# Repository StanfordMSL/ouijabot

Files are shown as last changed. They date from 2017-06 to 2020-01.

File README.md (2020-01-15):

# ouijabot

The ouijabot is an omnidirectional ground robot platform designed for general experiments in the plane, including 2D SLAM, collaborative manipulation, and pursuit-evasion. The platform's holonomic dynamics allow it to be well-modeled with a single-integrator model, which make it ideal for a wide variety of planar control and navigation tasks.

The hardware consists of 4 DC motors, which drive omnidirectional wheels, and an embedded Linux computer (Raspberry Pi). This project aims to completely open source all software and hardware. All communication is performed using ROS.

## Supported functions
Below are the features or capabilities of the ouijabot which
are currently supported.

---

### Onboard functions:
#### Velocity control
* Open-loop controller which seeks to track a desired robot velocity
  (combined linear and angular velocity).

#### Force control
* Closed-loop controller, which uses onboard current sensors to
  generate desired wrench (force and torque).

#### Sensors
* Measures current supplied to each motor by the motor drivers.
* Measures current linear acceleration and angular velocity via onboard IMU.

---
### Offboard functions:
#### Velocity teleoperation:
* ROS node which generates and publishes body-frame velocity
  commands via joystick input.

#### Force teleoperation:
* ROS node which generates and publishes body-frame force and torque commands
  via joystick input.

## Basic usage
Below we provide general instructions for how to utilize the supported features detailed above. Please see the code for additional details. All nodes typically run in a namespace set by the user's `$HOSTNAME` variable.

---

#### Velocity control
* **Onboard:** run `roslaunch ouijabot velocity_control.launch` to start the velocity control node (`velocity_control.py`). The node will subscribe to the topic `cmd_vel`, which uses messages of type `geometry_msgs/Twist`.
  * **Arguments:**
    * `cmdMode`: flag for desired throttle response of ouijabot. If set to `"equal"`, command axes are decoupled; throttle commands in one axis always correspond to the same speed, regardless of other axis commands. If set to `"max"`, then any command with l1-norm >= 1 is treated as "full speed"; at least one motor will run at max RPM. Allows for faster speeds overall of the ouijabot, but with less physical intuition behind commands.

* **Offboard:** to teleoperate ouijabot, run `roslaunch ouijabot_telop vel_telop.launch` to launch the velocity command node. The node will read joystick inputs and use them to generate velocity commands, which it publishes to `cmd_vel`.
  * **Arguments:**
    * `id`: index of ouijabot to be commanded. The node will remap the generic `cmd_vel` topic to `/ouijabot$(arg id)/cmd_vel` by default. Defaults to `1`.
    * `velMax_l`: scaling parameter for linear velocity commands. Should range between `0` and `1`, with `1` corresponding to max throttle available in hardware. Defaults to `1.0`.
    * `velMax_a`: scaling parameter for angular velocity commands. Same behavior as linear velocity scaling; defaults to `1.0`.
---
#### Force control
* **Onboard:** run `roslaunch ouijabot force_control.launch` to launch the force control node (`force_control.py`). The node will subscribe to the topic `cmd_wrench` which uses messages of type `geometry_msgs/Twist`. It uses onboard current sensors to run a closed-loop PID controller to generate the desired wrench.

    __*Note:*__ *`params.launch` must be run before `force_control.launch`; the PID parameters are set as ROS parameters in this file. This is typically done once, offboard, as part of robot setup. These parameters may easily be tuned by setting the ROS parameters manually.*

* **Offboard:** run `roslaunch ouijabot params.launch`, once, to set force controller parameters. Then run `roslaunch ouijabot_telop force_telop.launch` to teleoperate the ouijabot in force control mode. The node will read joystick inputs and use them to generate wrench commands, which it publishes to `cmd_wrench`.
  * **Arguments:**
    * `id`: index of ouijabot to be commanded. The node will remap the generic `cmd_vel` topic to `/ouijabot$(arg id)/cmd_vel` by default. Defaults to `1`.
    * `force_scale`: scaling parameter for max force command, in Newtons. Defaults to `100.0`.
    * `torque_scale`: scaling parameter for max torque command, in Newton-meters. Defaults to `5.0`.

---

#### Sensor readings
* **Current sensors:** run `roslaunch ouijabot current_read.launch` to run the current sensor node `current_read.py`. The node reads the current sensors on the motor controllers and publishes the values to the topic `current` as a vector of floats.

    __*Note:*__ *Do not run `current_read.py` at the same time as `force_control.py`; the force control node reads/publishes the current sensors as part of its control loop and the conflicting reads could cause timing errors.

* **IMU:** run `roslaunch ouijabot imu_read.launch` to run the IMU node `imu_read.py`. The node will read measurements from the IMU over I2C and publish them to the topic `imu` as messages of type `sensor_msgs/Imu`.

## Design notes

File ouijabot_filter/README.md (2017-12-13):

ouijabot_filter
===============

Author: Eric Cristofalo

Affiliation: Stanford University

Date Created: 2017/08/17; Date Last Modified: 2017/08/17

Tested on: ROS Kinetic

# Required ROS Packages:
* mocap_optitrack
* mocap_interface
* rviz
* rqt
* ouijabot_telop_cpp

# ouijabot_filter
This package contains an node that estimates the pose and odometry of the Ouijabot from published Optitrack data and the onboard IMU/wheel encoders. The estimation is performed with an EKF using the holonomic robot's 2nd order motion model. 

## Requirements

## Files
* filter.cpp
	* Reads raw Ouijabot data and Optitrack data to estimate odometry
    * Publishes ground truth odometry from Optitrack and estimated odometry from Ouijabot sensor data 
    * display_data_flag: integer indicator for printing data during testing (1 displays data)
    * use_optitrack_flag: integer indicator for dusing motion capture data into odometry estimate (not yet functional)
		* wheel_radius
		* body_radius
    * pos_covariance: double for position covariance
    * orient_covariance: double for orientation covariance
    * vel_covariance: double for velocity covariance
    * rot_rate_covariance: double for rotation rate covariance
    * accel_covariance: double for acceleration covariance
    * ROT_accel_covariance: double for rotation acceleration covariance
		* wheel_measurement_covariance
		* gyro_measurement_covariance
		* accel_measurement_covariance

* filter.launch
    * ROS launch file that launches the mocap_optitrack, rviz, rqt, and filter nodes simulaneously. The ground truth and odometry estimates are visualized in RViz. The state estimate is plotted against the ground truth using rqt.

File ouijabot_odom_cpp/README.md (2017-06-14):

ouijabot_odom_cpp
===============

Author: Eric Cristofalo

Affiliation: Stanford University

Date Created: 2017/06/13; Date Last Modified: 2017/06/13

Tested on: ROS Kinetic

# Required ROS Packages:
* mocap_optitrack
* mocap_interface
* joy
* rviz
* ouijabot_telop_cpp

# ouijabot_odom_cpp
This package contains an node that estimates the odometry of the Ouijabot from published wheel velocities. In the future, we should add a Kalman filter to fuse wheel encoders, IMU, and noisy GPS (motion capture) data.  

## Requirements

## Files
* odom.cpp
	* Reads raw Ouijabot data and Optitrack data to estimate odometry
    * Publishes ground truth odometry from Optitrack and estimated odometry from Ouijabot sensor data 
    * DISPLAY_DATA_BOOL: integer indicator for printing data during testing (1 displays data)
    * USE_OPTITRACK_BOOL: integer indicator for dusing motion capture data into odometry estimate (not yet functional)
    * POSITION_COVARIANCE: double for position covariance
    * ORIENTATION_COVARIANCE: double for orientation covariance
    * VELOCITY_COVARIANCE: double for velocity covariance
    * ROTATION_RATE_COVARIANCE: double for rotation rate covariance
* odom.launch
    * ROS launch file that launches the mocap_optitrack, rviz, and odom nodes simulaneously. The ground truth and odometry estimates are visualized in RViz.

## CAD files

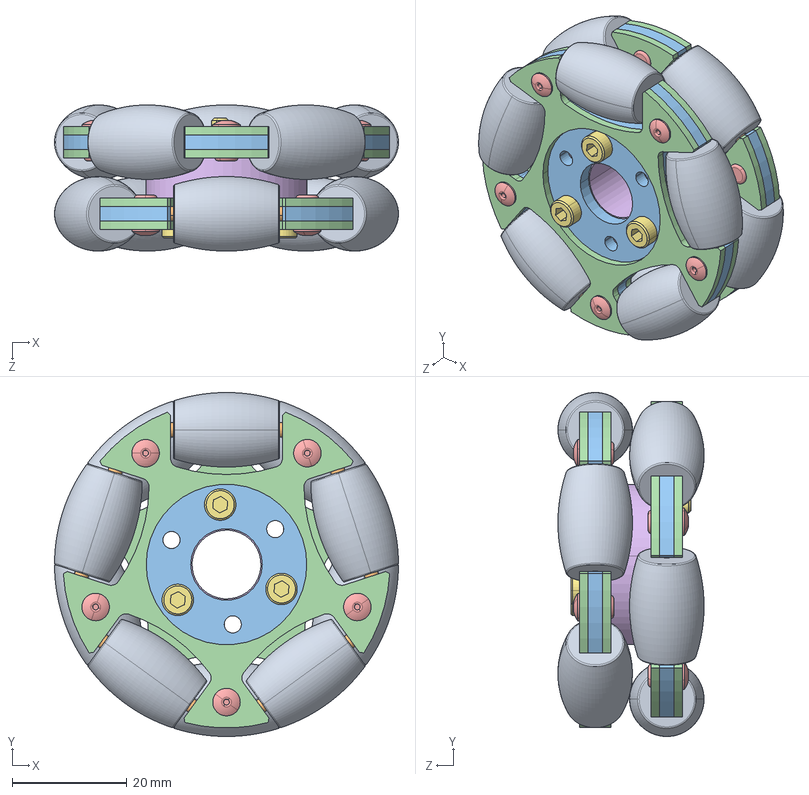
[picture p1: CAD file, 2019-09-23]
Hardware/CAD/omni-wheel-60mm.SLDASM
60.0 x 60.0 x 25.5 mm
60mm90__5______-______(A__).STEP x 10
60mm90__5______-______-__(A__).STEP x 10
60mm90__5______-____________(A__).STEP x 2
60mm90__5______-__________(A__).STEP x 4
____3X5.STEP x 10
60mm90__5______-__________(A__)-0.STEP
__________(M3X20).STEP x 3

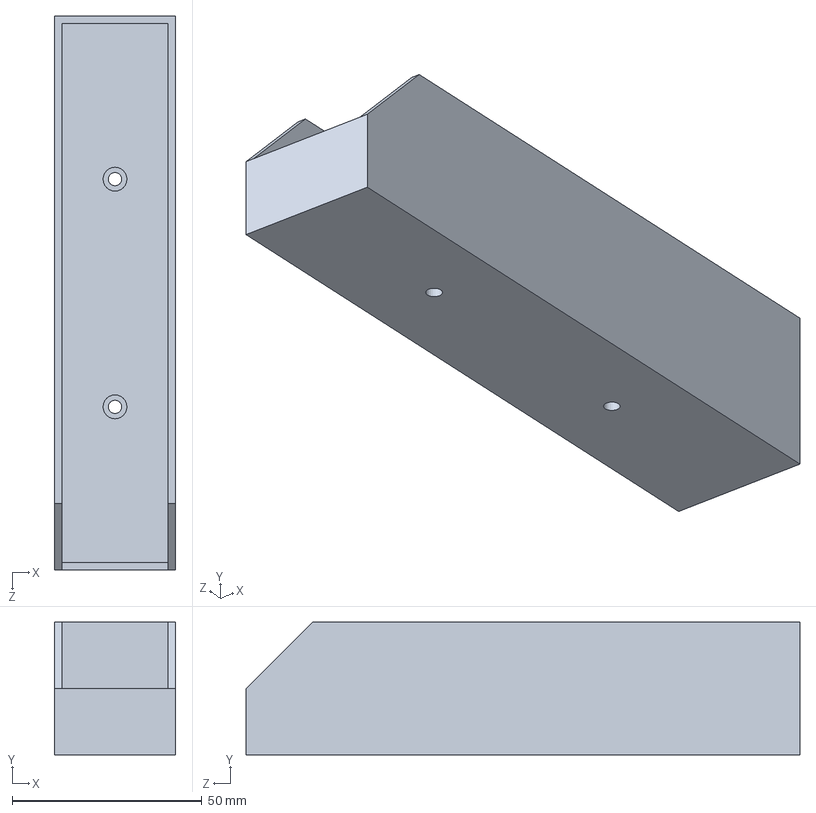
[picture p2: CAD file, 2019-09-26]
Hardware/CAD/battery-holder.SLDPRT
32.0 x 35.0 x 146.0 mm

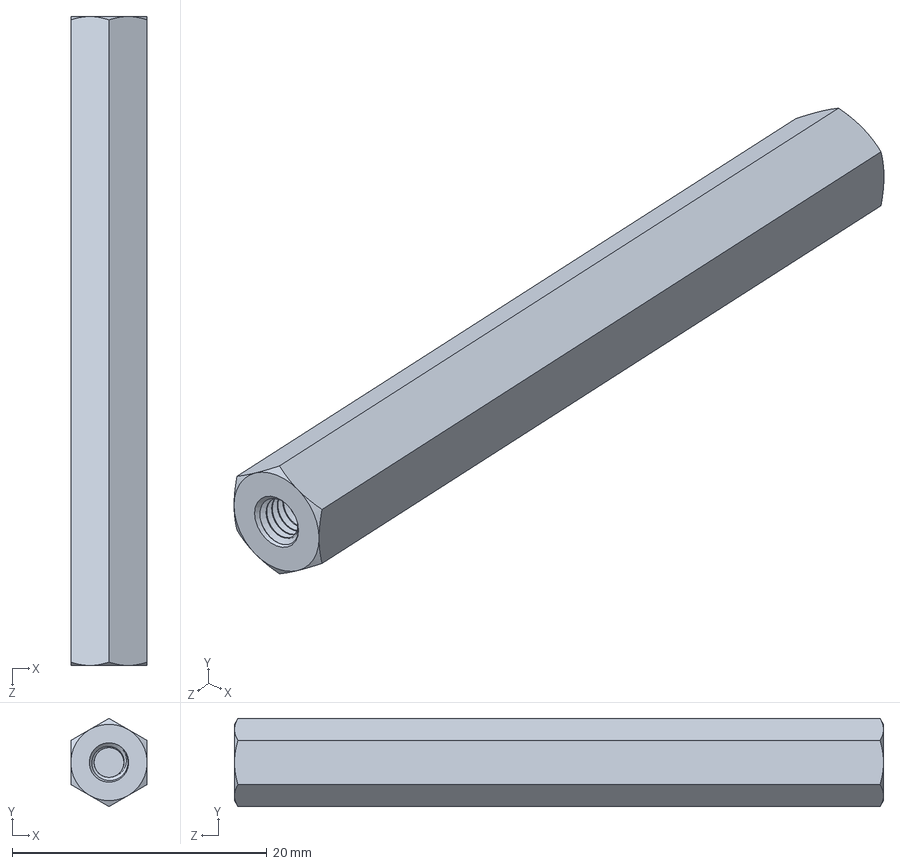
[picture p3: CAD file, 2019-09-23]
Hardware/CAD/standoff-51mm.SLDPRT
6.00 x 6.93 x 51.0 mm

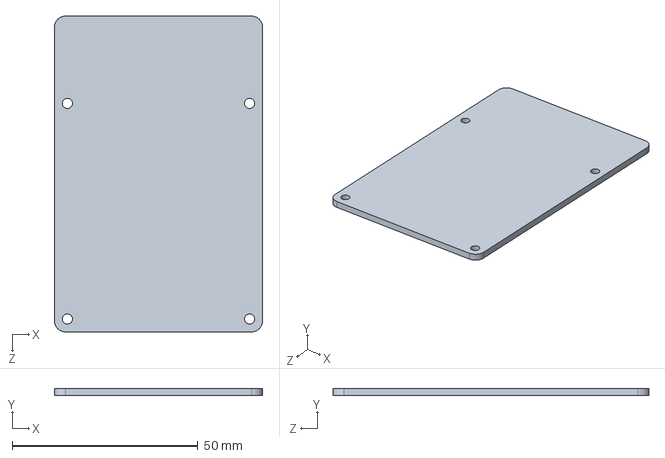
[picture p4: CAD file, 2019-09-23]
Hardware/CAD/raspberry_pi.SLDPRT
56.0 x 2.00 x 85.0 mm

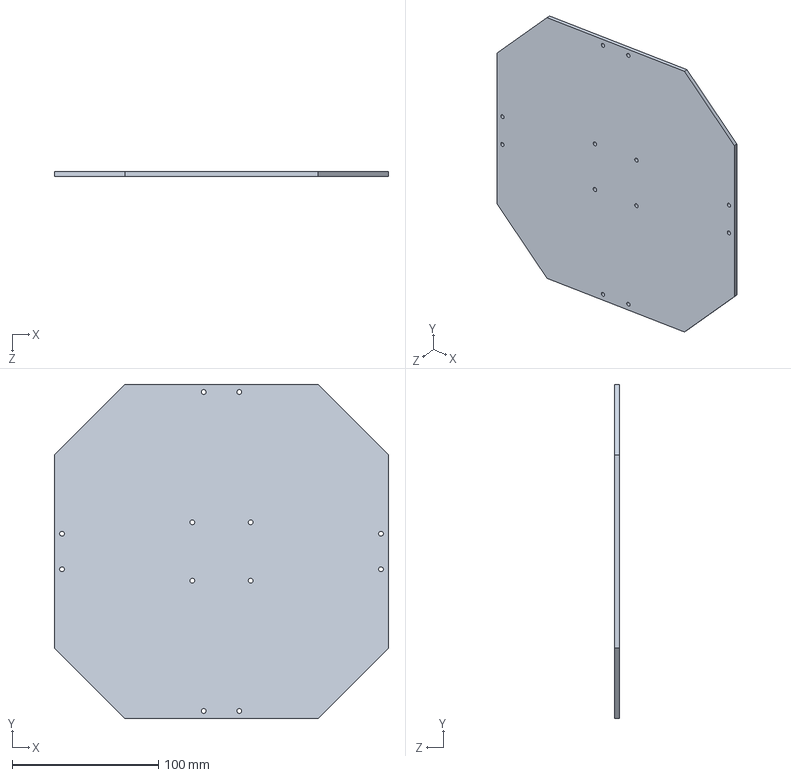
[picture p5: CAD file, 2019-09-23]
Hardware/CAD/lid.sldprt
228.6 x 228.6 x 3.17 mm

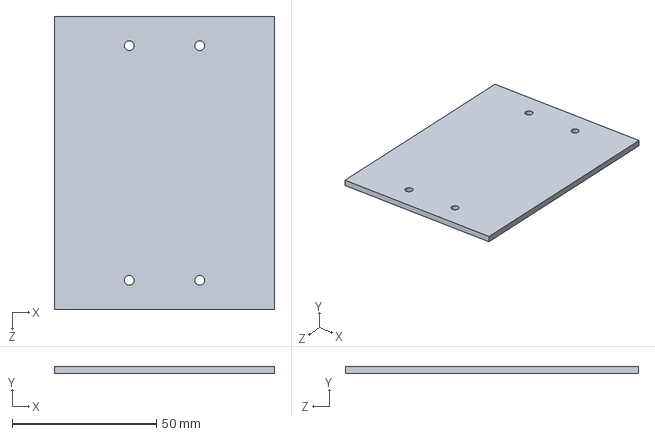
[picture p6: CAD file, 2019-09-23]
Hardware/CAD/wall.SLDPRT
76.2 x 2.54 x 101.6 mm

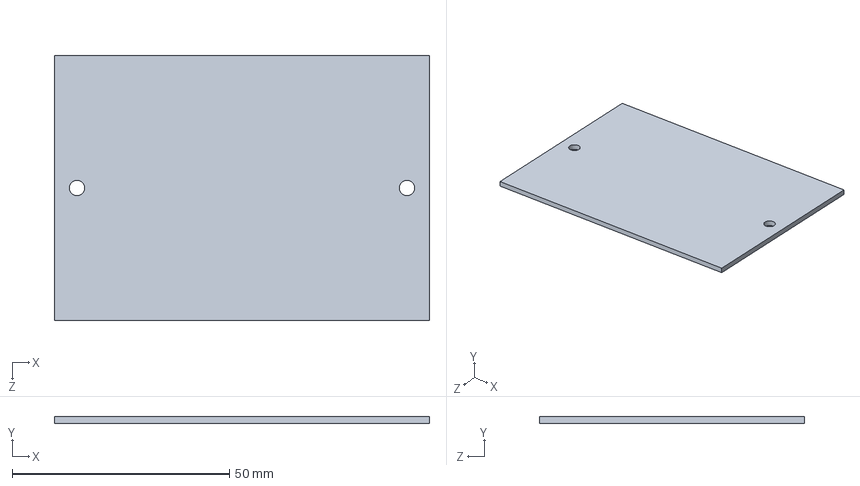
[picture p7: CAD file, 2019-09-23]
Hardware/CAD/protoboard.SLDPRT
86.4 x 1.60 x 61.0 mm

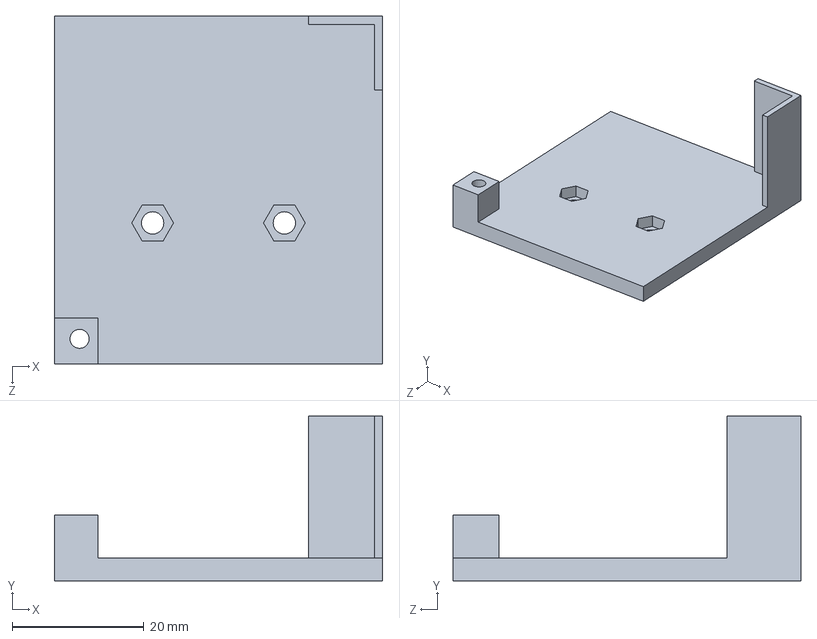
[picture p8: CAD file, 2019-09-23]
Hardware/CAD/motor-controller-holder-arduino-horizontal.SLDPRT
49.8 x 25.0 x 52.8 mm

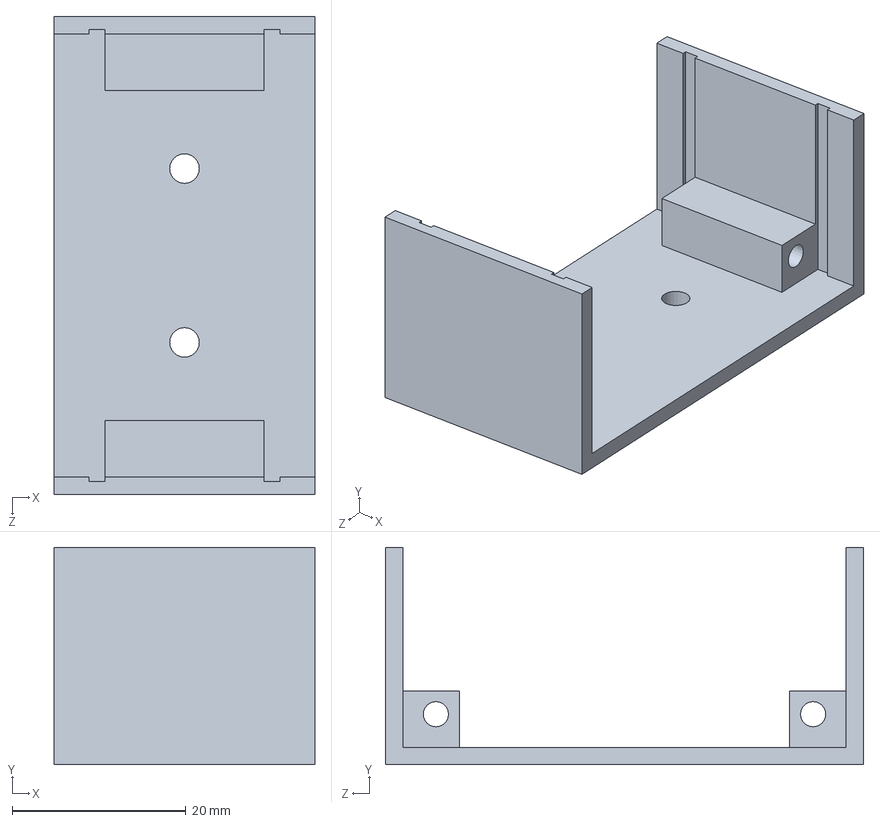
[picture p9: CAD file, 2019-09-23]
Hardware/CAD/motor-controller-holder-arduino.SLDPRT
30.0 x 25.0 x 55.0 mm

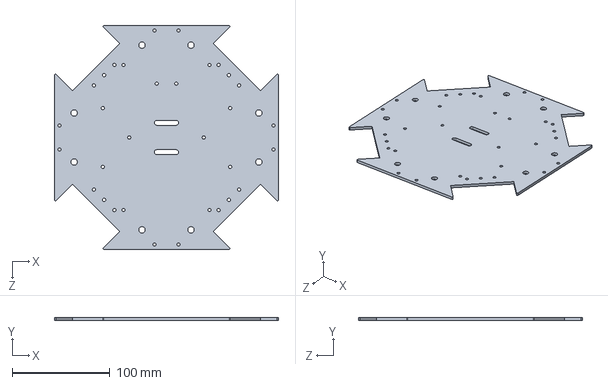
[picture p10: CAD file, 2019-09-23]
Hardware/CAD/base.SLDPRT
228.6 x 3.00 x 228.6 mm

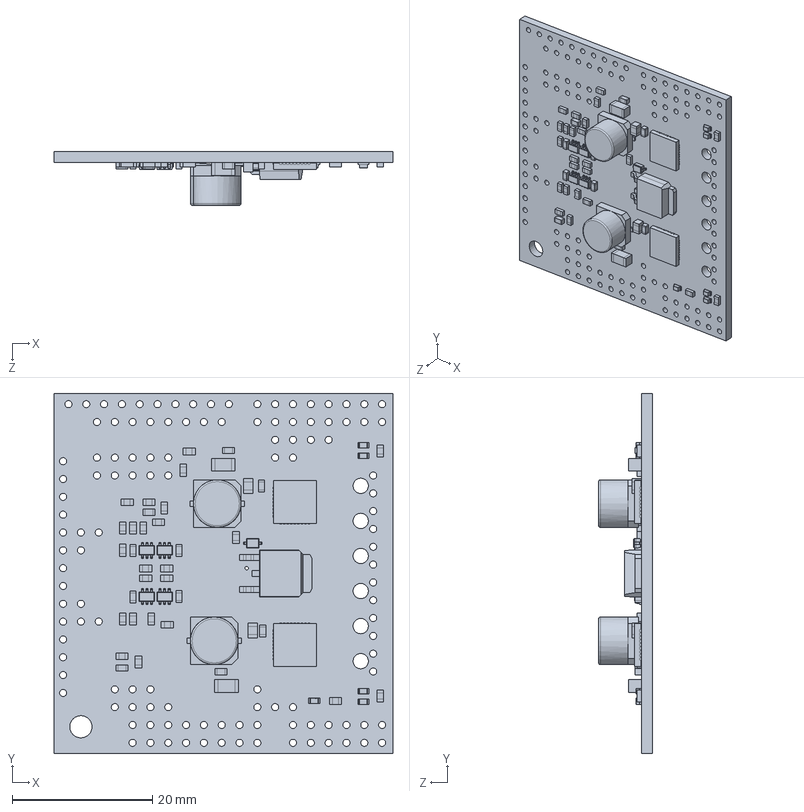
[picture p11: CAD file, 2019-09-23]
Hardware/CAD/motor-driver-pololu-tb9051ftg.SLDPRT
48.3 x 51.3 x 7.67 mm

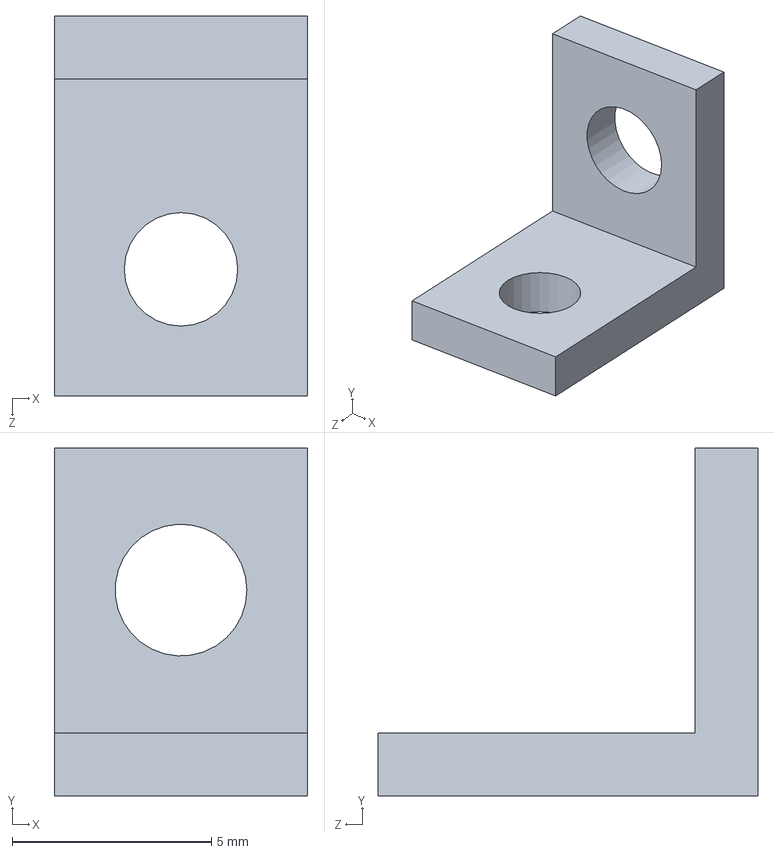
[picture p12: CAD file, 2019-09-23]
Hardware/CAD/angle-bracket.SLDPRT
6.35 x 8.71 x 9.53 mm

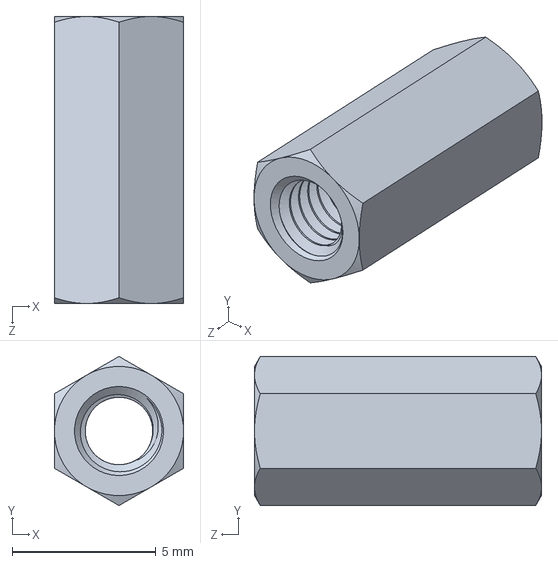
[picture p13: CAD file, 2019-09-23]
Hardware/CAD/standoff-10mm.SLDPRT
4.50 x 5.20 x 10.0 mm

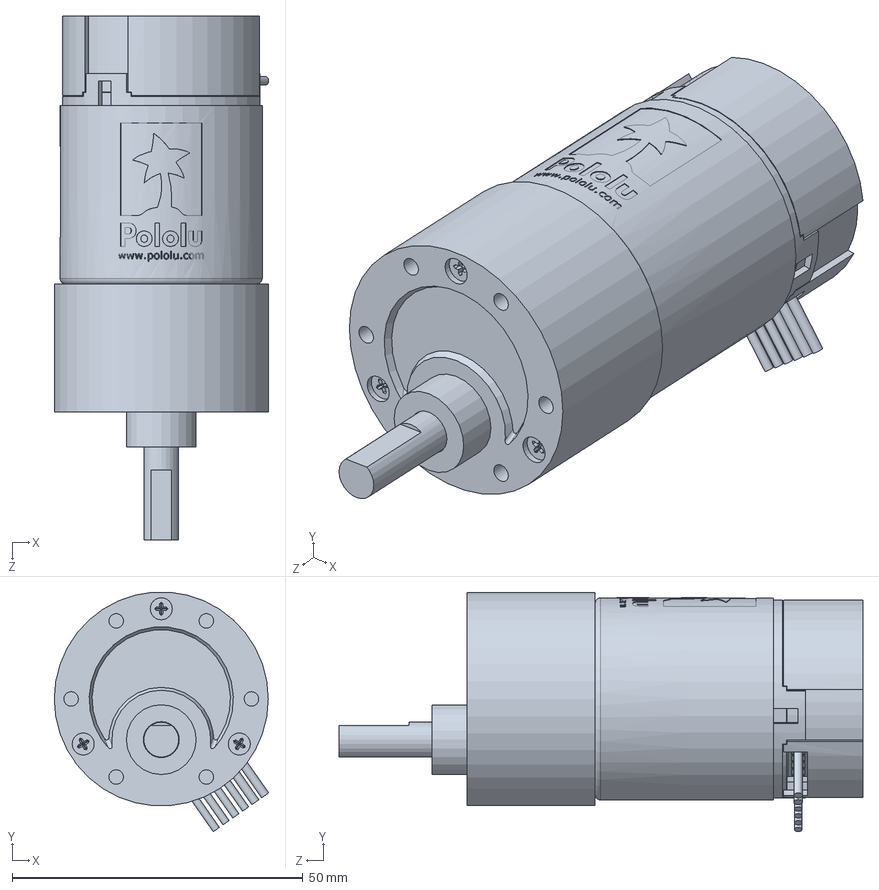
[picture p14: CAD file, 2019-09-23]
Hardware/CAD/motor-pololu-2823.SLDPRT
36.9 x 41.2 x 90.1 mm

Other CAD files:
Hardware/CAD/motor-mount-pololu-1995.SLDPRT
Hardware/CAD/level2-plate.SLDPRT

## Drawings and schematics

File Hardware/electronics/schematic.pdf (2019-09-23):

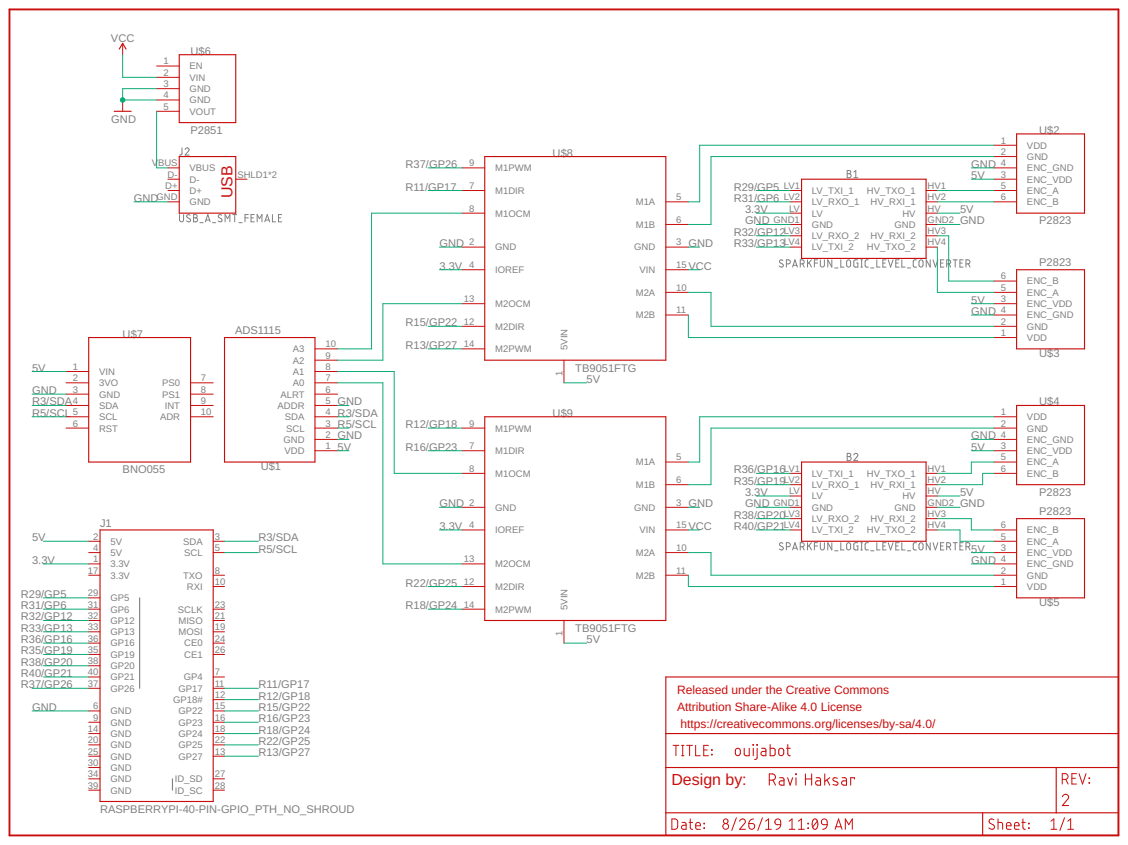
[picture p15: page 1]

Released under the Creative Commons Attribution Share-Alike 4.0 License

https://creativecommons.org/licenses/by-sa/4.0/

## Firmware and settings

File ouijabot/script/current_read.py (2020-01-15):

#!/usr/bin/python3

"""ROS node which reads and publishes current sensor values.

Module uses adafruit packages to read current sensors from motor control boards
over I2C. Uses a try-except block to catch bad I2C reads. Publishes current
values to the 'current' topic under the node's namespace.
"""

import rospy
import board
import busio
import adafruit_ads1x15.ads1015 as ADS
from adafruit_ads1x15.analog_in import AnalogIn
from std_msgs.msg import Float64MultiArray

i2c = busio.I2C(board.SCL, board.SDA) #create i2c object
ads = ADS.ADS1015(i2c) #create ads object

#setup channels for each current sensor
chan0 = AnalogIn(ads,ADS.P0)
chan1 = AnalogIn(ads,ADS.P1)
chan2 = AnalogIn(ads,ADS.P2)
chan3 = AnalogIn(ads,ADS.P3)

if __name__=="__main__":
	rospy.init_node('current')
	pub = rospy.Publisher('current',Float64MultiArray,queue_size=10)
	r = rospy.Rate(100) #TODO(Preston): make this a ROS parameter
	while not rospy.is_shutdown():
        try: #try to read current sensor
            msg = Float64MultiArray(data=[chan0.voltage,chan1.voltage,chan2.voltage,chan3.voltage])
            pub.publish(msg)
        except: #this read can fail; 
            rospy.logwarn('current read error')
		r.sleep()

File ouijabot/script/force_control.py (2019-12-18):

#!/usr/bin/env python3
import RPi.GPIO as io
import rospy
import numpy as np

from geometry_msgs.msg import Twist

import board
import busio
import adafruit_ads1x15.ads1015 as ADS
from adafruit_ads1x15.analog_in import AnalogIn
from std_msgs.msg import Float64MultiArray

sign = lambda x: (1,-1)[x<0]


class Ouijabot():
	def __init__(self):
		self.pwm_nos = [26,27,18,24]
		self.dir_pins = [17,22,23,25]
		self.pwm_pins = []
		for i in range(0,4):
			io.setup(self.pwm_nos[i],io.OUT)
			io.setup(self.dir_pins[i],io.OUT)
			self.pwm_pins.append(io.PWM(self.pwm_nos[i], 1e3))
			self.pwm_pins[i].start(0)
			io.output(self.dir_pins[i],io.HIGH)

		self.throttles = [0.,0.,0.,0.] #list of throttles for motors (in percent, [-100.,100.])
		self.curr_des = np.array([0.,0.,0.,0.]) #list of desired currents for motors
		self.currents = np.array([0.,0.,0.,0.]) #list of measured currents

		self.err_prev = np.array([0.,0.,0.,0.]) #last error -- used for 'd' term
		self.err_int = np.array([0.,0.,0.,0.]) #integral of error -- used for 'i' term

		#parameters
		self.maxDelay = rospy.get_param('~maxDelay')
		self.cmdFreq = rospy.get_param('~cmdFrq')
		self.currFreq = rospy.get_param('~currFrq')
		self.cmdRate = rospy.Rate(self.cmdFreq)
		self.cmdTime = rospy.get_time()

		#physical constants
		self.rW = rospy.get_param('/rW') #wheel radius, m
		self.rB = rospy.get_param('/rB') #body radius, m
		self.kMotor = rospy.get_param('/kMotor')*rospy.get_param('/fudgefactor') #motor constant, N*m/Amp
		self.kF = kF = np.sqrt(2)*self.kMotor/(2*self.rW) #N/Amp
		self.kT = kT = self.kF*self.rB #N*m/Amp

		#controller params
		self.kP = rospy.get_param('/kP') #proportional constant 
		self.kI = rospy.get_param('/kI') #integral constant
		self.kD = rospy.get_param('/kD') #derivative constant
		self.kFF = rospy.get_param('/kFF') #feed-forward constant
		self.iDec = rospy.get_param('/iDec') #factor to wind down integral term
		self.filt = rospy.get_param('/currFilt') #filtering factor for current measurements
		self.db = rospy.get_param('/currDB') #current measurement deadband

		#setup allocation matrix
		self.A = A = np.array([[kF,-kF,-kF,kF],[-kF,-kF,kF,kF],[kT,kT,kT,kT]])
		self.A_wrench = A.T@np.linalg.inv(A @ A.T)

		#setup current i/o
		self.curr_pub =  rospy.Publisher('current',Float64MultiArray,queue_size=0)
		self.cd_pub = rospy.Publisher('curr_des',Float64MultiArray,queue_size=0)
		self.i2c = busio.I2C(board.SCL, board.SDA)
		self.ads = ADS.ADS1015(self.i2c)

		self.chan0 = AnalogIn(self.ads,ADS.P0)
		self.chan1 = AnalogIn(self.ads,ADS.P1)
		self.chan2 = AnalogIn(self.ads,ADS.P2)
		self.chan3 = AnalogIn(self.ads,ADS.P3)

		self.channels = [self.chan0,self.chan1,self.chan2,self.chan3]

		#setup timers for control read/write
		self.cmdTimer = rospy.Timer(rospy.Duration(1/self.cmdFreq),self.run)
		self.currTimer = rospy.Timer(rospy.Duration(1/self.currFreq),self.current_callback)
		self.cdTimer = rospy.Timer(rospy.Duration(1/self.currFreq),self.cd_callback)

		#subscribers
		self.cmd_callback = rospy.Subscriber("cmd_wrench", Twist, self.cmd_wrench_callback)

		#TODO: implement 'active' functionality

	def cmd_wrench_callback(self,data):
		fx = data.linear.x
		fy = data.linear.y
		torque = data.angular.z

		self.cmdTime = rospy.get_time()

		Wd = np.array([fx,fy,torque]) #desired wrench

		self.curr_des = self.A_wrench @ Wd #change wrench to motor currents

	def cd_callback(self,event):
		msg = Float64MultiArray(data=self.curr_des)
		self.cd_pub.publish(msg)

	def current_callback(self,event):
		data = []
		try:
			for i in range(0,4):
				data.append(sign(self.throttles[i])*self.channels[i].voltage)
			self.currents = self.currents + self.filt*(np.array(data)-self.currents)
		except:
			rospy.logwarn('current read error')
		#self.currents[np.where(np.abs(self.currents)<=self.db)] = 0.0
		msg = Float64MultiArray(data=self.currents)
		self.curr_pub.publish(msg)

	def stop_bot(self):
		for i in range(0,4):
			self.pwm_pins[i].ChangeDutyCycle(0)

	def bot_shutdown(self):
		self.stop_bot()
		for i in range(0,4):
			self.pwm_pins[i].stop()
		io.cleanup()

	def run(self,event):
		if (rospy.get_time() - self.cmdTime) > self.maxDelay:
			self.stop_bot()
		else: #TODO: ifactive
			#calculate error terms
			e = self.currents - self.curr_des #current error
			de = e - self.err_prev #error difference
			#a thought: if clipping, stop winding up integrator
			self.err_int = err_int = self.iDec*self.err_int + e #running error (integral term)

			input = self.kFF*self.curr_des - self.kP*e - self.kD*de - self.kI*err_int
			self.throttles = np.clip(input,-100.,100.)
			self.throttles[np.where(np.abs(self.throttles)<=1.0)] = 0.

			for i in range(0,4):
				if self.throttles[i] > 0:
					io.output(self.dir_pins[i],io.HIGH)
				else:
					io.output(self.dir_pins[i],io.LOW)
				self.pwm_pins[i].ChangeDutyCycle(abs(self.throttles[i]))

			self.err_prev = e #store previous error term for derivative term

if __name__=="__main__":
	rospy.init_node('ouijabot')
	io.setmode(io.BCM)
	io.setwarnings(False)
	try:
		Ouijabot()
		rospy.logwarn("Starting up.")
		rospy.spin()
	except rospy.ROSException as e:
		rospy.logwarn("Shutting down.")
		self.bot_shutdown()
		raise e

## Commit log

2017-06-14 Added an odometry node for estimating odometry from onboard Ouijabot sensors. Rough stages, still needs tuning.
2017-06-16 Finsihed odometry for outputting odometry from mocap data. Odometry from raw wheel speeds needs to be finished.
2017-08-18 Small filter updates, still requires testing.
2017-12-13 Working filter for pose estimation post-ICRA commit
2018-04-24 Update README.md
    Add IMU calibration instruction
2018-09-18 updated filter, needto check coordinate system again
2019-02-05 Control safety (#1)
    * added exceptions for failure cases
    * added serial buffer to class as member
    * added persistent velocity pub for the telop node
2019-02-16 add ouijabot PCB schematic
2019-04-10 minor fix on desired angle parse, added test framework for testing ouijabot functions
2019-05-01 Made 2 significant changes. 1) the ID of the robot being controlled can now be set as an argument when calling telop.launch. 2) added code to telop.cpp so limits on the maximum linear & angular veloc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
2019-07-16 Started re-design of base plate.
    [base.SLDPRT]
2019-07-17 Added slots for cables, mount holes for motor controller board holder.
    [base.SLDPRT]
2019-07-17 Created holder for motor controller boards.
    [motor-controller-holder-arduino.SLDPRT]
2019-07-18 Added wall bracket and battery holder holes.
    [base.SLDPRT]
2019-07-19 Updated parts for clearance in assembly.
    [base.SLDPRT, motor-controller-holder-arduino.SLDPRT]
2019-07-19 Added new parts for assembly.
    [angle-bracket.SLDPRT, battery-holder.SLDPRT, motor-driver-pololu-tb9051ftg.SLDPRT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]
2019-07-19 First pass at full assembly.
    [ouijabot.SLDASM]
2019-07-22 Finished plates for electronics and walls, and added both to the full assembly.
    [battery-holder.SLDPRT, level2-plate.SLDPRT, motor-controller-holder-arduino.SLDPRT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]
2019-07-25 Increased countersink hole size for battery holder and modified base wall holes for better compatibility with existing holes.
    [base.SLDPRT, battery-holder.SLDPRT, wall.SLDPRT]
2019-08-14 Created modified motor controller holder to reduce height of electronics plate.
    [motor-controller-holder-arduino-horizontal.SLDPRT]
2019-08-17 Added EAGLE project for schematic.
    [ouijabot.sch]
2019-08-17 Added ADC to schematic.
    [ouijabot.sch]
2019-08-17 Finished adding parts to library.
    [ouijabot.sch]
2019-08-17 Added current sense pins to motor drivers.
    [ouijabot.sch]
2019-08-17 Added USB header to schematic.
    [ouijabot.sch]
2019-08-17 First pass of completed schematic.
    [ouijabot.sch]
2019-08-26 Changed IMU and ADC power from 3.3v to 5v due to Raspberry Pi limitations.
    [ouijabot.sch]
2019-09-17 Modified electronics plate for easier assembly and created a lid.
    [base.SLDPRT, level2-plate.SLDPRT, lid.sldprt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]
2019-09-23 added current read
2019-09-26 Improved hole clearances.
    [battery-holder.SLDPRT]
2019-10-21 added imu read + debugged other nodes
2019-11-13 added current read to mcu for sign info
2019-12-11 fixed motor signs in fc
2019-12-18 added try-except block for current read errors
2019-12-19 added try-except for i2c read
2020-01-13 added different velocity control mode
2020-01-15 big repo reorganization; rewrote README.md to document current code. this is likely a breaking change due to node and launchfile renames.
